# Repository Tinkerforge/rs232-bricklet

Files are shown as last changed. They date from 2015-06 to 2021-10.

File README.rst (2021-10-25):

RS232 Bricklet
==============

This repository contains the firmware source code and the hardware design
files. The documentation generator configs can be found at
https://github.com/Tinkerforge/generators

Repository Content
------------------

software/:
 * examples/: Examples for all supported languages
 * build/: Compiled files
 * src/: Source code of firmware
 * Makefile: Makefile to build project

hardware/:
 * Contains KiCad project files and additionally schematics as PDF

datasheets/:
 * Contains datasheets for sensors and complex ICs that are used

Hardware
--------

The hardware is designed with the open source EDA Suite KiCad
(http://www.kicad.org). Before you are able to open the files,
you have to install the Tinkerforge kicad-libraries
(https://github.com/Tinkerforge/kicad-libraries). You can either clone
them directly in hardware/ or clone them in a separate folder and
symlink them into hardware/
(ln -s kicad_path/kicad-libraries project_path/hardware). After that you
can open the .pro file in hardware/ with KiCad and from there view and
modify the schematics and the PCB layout.

Software
--------

If you want to do your own Brick/Bricklet firmware development we highly
recommend that you use our build environment setup script and read the
tutorial (https://www.tinkerforge.com/en/doc/Tutorials/Tutorial_Build_Environment/Tutorial.html).

To compile the C code we recommend you to install the newest GNU Arm Embedded
Toolchain (https://launchpad.net/gcc-arm-embedded/+download).
You also need to install bricklib (https://github.com/Tinkerforge/bricklib)
and brickletlib (https://github.com/Tinkerforge/brickletlib).

You can either clone it directly in software/src/ or clone it in a
separate folder and symlink it into software/src/
(ln -s bricklib_path/bricklib project_path/software/src/ and
ln -s brickletlib_path/brickletlib project_path/software/src/).
Finally make sure to have CMake installed
(http://www.cmake.org/cmake/resources/software.html).

After that you can build the firmware by invoking make in software/.
The firmware (.bin) can then be found in software/build/ and uploaded
with brickv (click button "Flashing" on start screen).

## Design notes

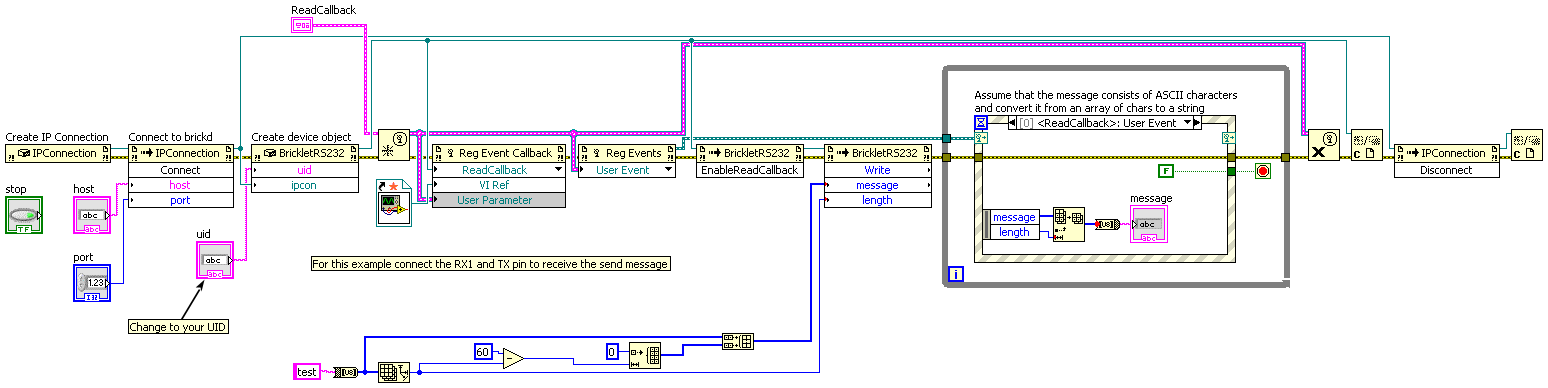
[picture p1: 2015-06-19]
software/examples/labview/Example Loopback.vi.png

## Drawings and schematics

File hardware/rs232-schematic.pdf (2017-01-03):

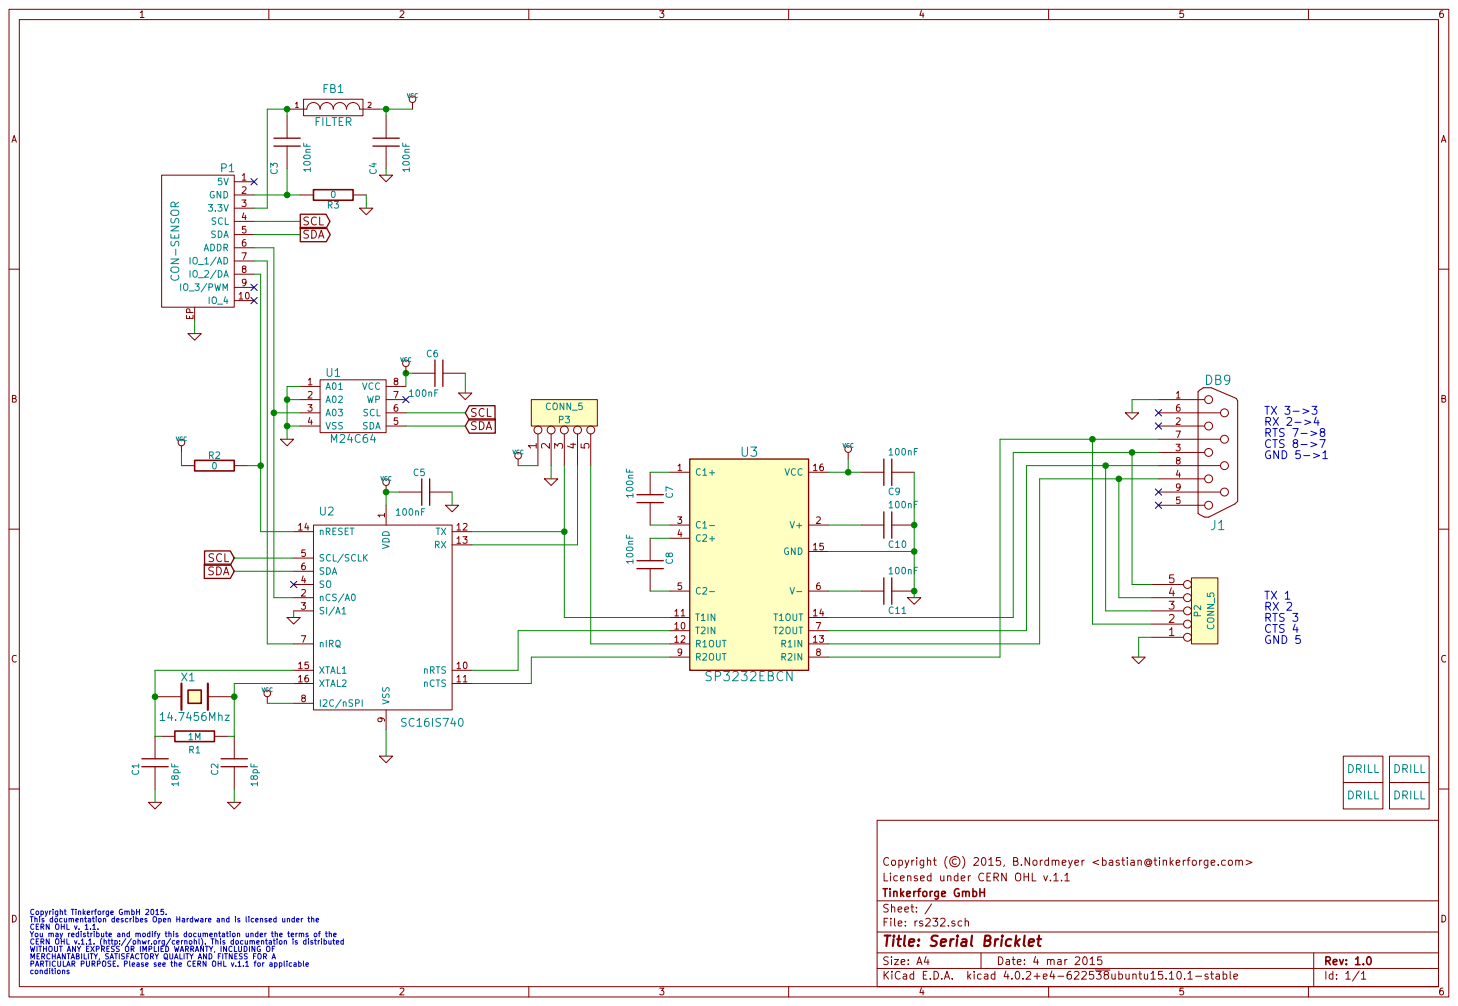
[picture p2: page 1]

Licensed under CERN OHL v.1.1 Copyright (©) 2015, B.Nordmeyer <bastian@tinkerforge.com> VDD

Id: 1/1 Title: Serial Bricklet File: rs232.sch Sheet: / Tinkerforge GmbH

Copyright Tinkerforge GmbH 2015. This documentation describes Open Hardware and is licensed under the CERN OHL v. 1.1. You may redistribute and modify this documentation under the terms of the CERN OHL v.1.1. (http://ohwr.org/cernohl). This documentation is distributed WITHOUT ANY EXPRESS OR IMPLIED WARRANTY, INCLUDING OF MERCHANTABILITY, SATISFACTORY QUALITY AND FITNESS FOR A

PARTICULAR PURPOSE. Please see the CERN OHL v.1.1 for applicable

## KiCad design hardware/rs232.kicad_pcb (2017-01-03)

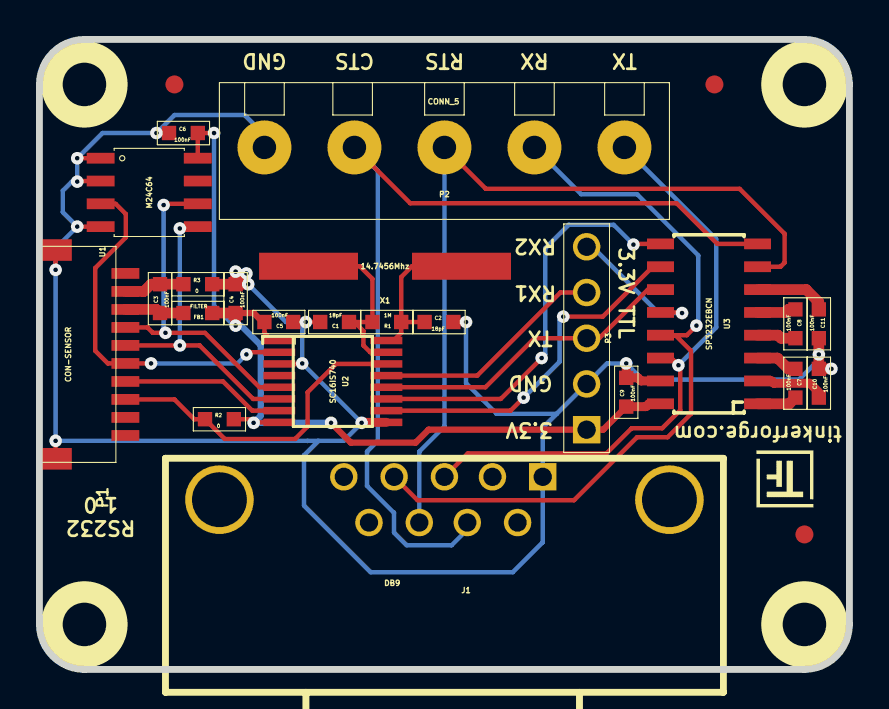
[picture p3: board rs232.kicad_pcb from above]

Board: 2 copper layers, 45.0 x 35.0 mm, 32 parts (0 on the bottom side), 26 nets.

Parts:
C1, C2: 18pF; 0603
C3, C4, C5, C6, C7, C8, C9, C10, C11: 100nF; 0603
FB1: FILTER; 0603
Fiducial_Mark: VAL**; Fiducial_Mark
Fiducial_Mark#2, Fiducial_Mark#3: VAL**; Fiducial_Mark
J1: DB9; SUB09-EU
P1: CON-SENSOR
P2: CONN_5; AKL_5_5
P3: CONN_5; pin_array_5x1
R1: 1M; 0603
R2, R3: 0; 0603
U1: M24C64; SOIC8
U2: SC16IS740; TSSOP16
U3: SP3232EBCN; SOIC16
U4, U5, U6, U7: DRILL; DRILL_NP
VAL: WEEE_7mm
VAL#2: CE_5mm
X1: 14.7456Mhz; HC49_US

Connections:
GND: C1.1, C2.1, C4.1, C5.2, C6.2, C9.1, C10.1, C11.1, J1.1, P1.EP, P2.1, P3.2, R3.1, U1.1, U1.2, U1.4, U2.3, U2.9, U3.15
unnamed: C1.2, R1.1, U2.15, X1.2
unnamed: C2.2, R1.2, U2.16, X1.1
unnamed: C3.1, P1.2, R3.2
unnamed: C3.2, FB1.1, P1.3
unnamed: C7.1, U3.1
unnamed: C7.2, U3.3
unnamed: C8.1, U3.4
unnamed: C8.2, U3.5
unnamed: C10.2, U3.2
unnamed: C11.2, U3.6
unnamed: J1.3, P2.5, U3.14
unnamed: J1.4, P2.4, U3.13
unnamed: J1.7, P2.2, U3.8
unnamed: J1.8, P2.3, U3.7
unnamed: P1.6, U1.3, U2.2
unnamed: P1.7, U2.7
unnamed: P1.8, R2.2, U2.14
unnamed: P3.3, U2.12, U3.11
unnamed: P3.4, U2.13
unnamed: P3.5, U3.12
unnamed: U2.10, U3.10
unnamed: U2.11, U3.9
SCL: P1.4, U1.6, U2.5
SDA: P1.5, U1.5, U2.6
VCC: C4.2, C5.1, C6.1, C9.2, FB1.2, P3.1, R2.1, U1.8, U2.1, U2.8, U3.16

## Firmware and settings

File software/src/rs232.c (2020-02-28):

/* rs232-bricklet
 * Copyright (C) 2015 Olaf Lüke <olaf@tinkerforge.com>
 *
 * rs232.c: Implementation of RS232 Bricklet messages
 *
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
 * You should have received a copy of the GNU Lesser General Public
 * License along with this library; if not, write to the
 * Free Software Foundation, Inc., 59 Temple Place - Suite 330,
 * Boston, MA 02111-1307, USA.
 */

#include "rs232.h"

#include "brickletlib/bricklet_entry.h"
#include "bricklib/bricklet/bricklet_communication.h"
#include "bricklib/utility/util_definitions.h"
#include "config.h"

#define NUM_BAUDRATES 13
#define NUM_PARITIES 5
#define NUM_STOPBITS 2
#define NUM_WORDLENGTH 4
#define NUM_FLOWCONTROL 2

const uint16_t baudrates[NUM_BAUDRATES] = {
	3072, //    300 baud
	1536, //    600 baud
	768,  //   1200 baud
	384,  //   2400 baud
	192,  //   4800 baud
	96,   //   9600 baud
	64,   //  14400 baud
	48,   //  19200 baud
	32,   //  28800 baud
	24,   //  38400 baud
	16,   //  57600 baud
	8,    // 115200 baud
	4     // 230400 baud
};

const uint8_t parities[NUM_PARITIES] = {
	0, // None
	1 << 3, // Odd
	(1 << 3) | (1 << 4), // Even
	(1 << 3) | (1 << 5), // Forced Parity 1
	(1 << 3) | (1 << 4) | (1 << 5), // Forced Parity 0
};

const uint8_t stopbits[NUM_STOPBITS] = {
	0, // 1 Stopbit
	1 << 2 // 2 Stopbits
};

const uint8_t wordlength[NUM_WORDLENGTH] = {
	0, // 5
	1 << 0, // 6
	1 << 1, // 7
	(1 << 0) | (1 << 1) // 8
};

const uint8_t hardware_flowcontrol[NUM_FLOWCONTROL] = {
	0, // Hardware Flow Control Disabled
	(1 << 6) | (1 << 7), // Hardware Flow Control Enabled
};

const uint8_t software_flowcontrol[NUM_FLOWCONTROL] = {
	0, // Software Flow Control Disabled
	(1 << 3) | (1 << 1), // Software Flow Control Enabled
};

uint8_t sc16is740_get_address(void) {
	if(BS->address == I2C_EEPROM_ADDRESS_HIGH) {
		return I2C_ADDRESS_HIGH;
	} else {
		return I2C_ADDRESS_LOW;
	}
}

uint8_t sc16is740_read_fifo(uint8_t *data) {
	int8_t length = BUFFER_SIZE-1 - size_out();
	uint8_t rxlvl = sc16is740_read_register(I2C_INTERNAL_ADDRESS_RXLVL);
	length = MIN(length, rxlvl);

	if(length <= 0) {
		return 0;
	}

	BA->TWID_Read(BA->twid,
	              sc16is740_get_address(),
	              I2C_INTERNAL_ADDRESS_RHR << 3,
	              1,
	              data,
	              length,
	              NULL);

	return length;
}

uint8_t sc16is740_read_register(const uint8_t address) {
	uint8_t value = 0;

	BA->TWID_Read(BA->twid,
	              sc16is740_get_address(),
	              address << 3,
	              1,
	              &value,
	              1,
	              NULL);

	return value;
}

void sc16is740_write_register(const uint8_t address, uint8_t value) {
	BA->TWID_Write(BA->twid,
	               sc16is740_get_address(),
	               address << 3,
	               1,
	               &value,
	               1,
	               NULL);
}

void sc16is740_reconfigure(void) {
	BrickletAPI *ba = BA;
	if(ba->mutex_take(*ba->mutex_twi_bricklet, 10)) {
		ba->bricklet_select(BS->port - 'a');

		// Write 0xBF to LCR to be able to access EFR
		sc16is740_write_register(I2C_INTERNAL_ADDRESS_LCR, 0xBF);

		// Enable or Disable Hardware Flow Control
		sc16is740_write_register(I2C_INTERNAL_ADDRESS_EFR, hardware_flowcontrol[BC->hardware_flowcontrol] | software_flowcontrol[BC->software_flowcontrol]);

		// Configure UART
		uint8_t lcr = stopbits[BC->stopbits-1] | parities[BC->parity] | wordlength[BC->wordlength-5];
		sc16is740_write_register(I2C_INTERNAL_ADDRESS_LCR, lcr);

		// Configure baudrate: ((14.7456 MHz * 1000000) / 1) /
		//                     (X baud * 16) = baudrates[BC->baudrate]
		lcr |= 1 << 7; // Divisor latch enable: LCR[7] = 1
		sc16is740_write_register(I2C_INTERNAL_ADDRESS_LCR, lcr);

		sc16is740_write_register(I2C_INTERNAL_ADDRESS_DLL, baudrates[BC->baudrate]&0xFF);
		sc16is740_write_register(I2C_INTERNAL_ADDRESS_DLH, (baudrates[BC->baudrate]>>8)&0xFF);

		lcr = sc16is740_read_register(I2C_INTERNAL_ADDRESS_LCR);
		lcr &= ~(1 << 7); // Divisor latch disable: LCR[7] = 0
		sc16is740_write_register(I2C_INTERNAL_ADDRESS_LCR, lcr);

		ba->bricklet_deselect(BS->port - 'a');
		ba->mutex_give(*ba->mutex_twi_bricklet);
	}
}

void sc16is740_init(void) {
	BrickletAPI *ba = BA;
	if(ba->mutex_take(*ba->mutex_twi_bricklet, 10)) {
		ba->bricklet_select(BS->port - 'a');

		// Enable RX and TX FIFOs: FCR[0] = 1
		sc16is740_write_register(I2C_INTERNAL_ADDRESS_FCR, 1 << 0);

		// Enable Receive Holding Register Interrupt: IER[0] = 1
		sc16is740_write_register(I2C_INTERNAL_ADDRESS_IER, 1 << 0);

		ba->bricklet_deselect(BS->port - 'a');
		ba->mutex_give(*ba->mutex_twi_bricklet);
	}
}

void constructor(void) {
	_Static_assert(sizeof(BrickContext) <= BRICKLET_CONTEXT_MAX_SIZE,
	               "BrickContext too big");

    BrickContext *bc = BC;

	PIN_NIRQ.type = PIO_INPUT;
	PIN_NIRQ.attribute = PIO_PULLUP;
	BA->PIO_Configure(&PIN_NIRQ, 1);

	// Always keep NRESET to high, with newer hardware versions
	// NRESET is directly connected to VCC. This is necessary to
	// prevent rare EMI problems that result in unexpected resets.
	PIN_NRESET.type = PIO_OUTPUT_1;
	PIN_NRESET.attribute = PIO_DEFAULT;
	BA->PIO_Configure(&PIN_NRESET, 1);

	bc->read_callback_enabled = false;
	bc->frame_readable_cb_frame_size = 0;
	bc->frame_readable_cb_already_sent = false;
	bc->in_sync = true;

	bc->baudrate = 11;
	bc->parity = 0;
	bc->stopbits = 1;
	bc->wordlength = 8;
	bc->hardware_flowcontrol = 0;
	bc->software_flowcontrol = 0;
	bc->error = 0;

	read_configuration_from_eeprom();
	sc16is740_init();
	sc16is740_reconfigure();
}

void destructor(void) {
}

uint8_t size_in(void) {
	BrickContext *bc = BC;
	if(bc->in_start == bc->in_end) {
		return 0;
	}

	if(bc->in_start < bc->in_end) {
		return bc->in_end - bc->in_start;
	}

	return (BUFFER_SIZE - bc->in_start) + bc->in_end;
}

uint8_t size_out(void) {
	BrickContext *bc = BC;
	if(bc->out_start == bc->out_end) {
		return 0;
	}

	if(bc->out_start < bc->out_end) {
		return bc->out_end - bc->out_start;
	}

	return (BUFFER_SIZE - bc->out_start) + bc->out_end;
}

bool new_char_out(char out) {
	BrickContext *bc = BC;
	bc->out[bc->out_end] = out;

	// If buffer is full, we ignore new char
	if((bc->out_end+1) % BUFFER_SIZE != bc->out_start) {
		bc->out_end = (bc->out_end + 1) % BUFFER_SIZE;
		return true;
	}

	return false;
}

bool get_char_in(char *c) {
	BrickContext *bc = BC;
	if(bc->in_start != bc->in_end) {
		*c = bc->in[bc->in_start];
		bc->in_start = (bc->in_start + 1) % BUFFER_SIZE;
		return true;
	}

	return false;
}

bool is_irq(void) {
	return (!(PIN_NIRQ.pio->PIO_PDSR & PIN_NIRQ.mask)) && (size_out() < (BUFFER_SIZE-1));
}

bool try_read_data(void) {
	while(is_irq()) {
		uint8_t buffer[59];
		uint8_t length = sc16is740_read_fifo(buffer);
		if(length == 0) {
			return false;
		}

		for(uint8_t i = 0; i < length; i++) {
			// We don't have to check return value here, sc16is740_read_fifo
			// already made sure that there is enough space in the buffer.
			new_char_out(buffer[i]);
		}
		return true;
	}

	return false;
}
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

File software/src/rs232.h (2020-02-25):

/* rs232-bricklet
 * Copyright (C) 2015 Olaf Lüke <olaf@tinkerforge.com>
 *
 * rs232.h: Implementation of RS232 Bricklet messages
 *
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
 * You should have received a copy of the GNU Lesser General Public
 * License along with this library; if not, write to the
 * Free Software Foundation, Inc., 59 Temple Place - Suite 330,
 * Boston, MA 02111-1307, USA.
 */

#ifndef RS232_H
#define RS232_H

#include <stdint.h>

#include "bricklib/com/com_common.h"

#define CONFIGURATION_EEPROM_POSITION (BRICKLET_PLUGIN_MAX_SIZE + 96)

#define FID_WRITE                    1
#define FID_READ                     2
#define FID_ENABLE_READ_CALLBACK     3
#define FID_DISABLE_READ_CALLBACK    4
#define FID_IS_READ_CALLBACK_ENABLED 5
#define FID_SET_CONFIGURATION        6
#define FID_GET_CONFIGURATION        7
#define FID_READ_CALLBACK            8
#define FID_ERROR_CALLBACK           9
#define FID_SET_BREAK_CONDITION      10
#define FID_SET_FRAME_READABLE_CALLBACK_CONFIGURATION 11
#define FID_GET_FRAME_READABLE_CALLBACK_CONFIGURATION 12
#define FID_FRAME_READABLE_CALLBACK 13
#define FID_READ_FRAME 14

#define MESSAGE_LENGTH 60

typedef struct {
	MessageHeader header;
} __attribute__((__packed__)) StandardMessage;

typedef struct {
	MessageHeader header;
	char message[MESSAGE_LENGTH];
	uint8_t length;
} __attribute__((__packed__)) Write;

typedef struct {
	MessageHeader header;
	uint8_t written;
} __attribute__((__packed__)) WriteReturn;

typedef struct {
	MessageHeader header;
} __attribute__((__packed__)) Read;

typedef struct {
	MessageHeader header;
	char message[MESSAGE_LENGTH];
	uint8_t length;
} __attribute__((__packed__)) ReadReturn;

typedef struct {
	MessageHeader header;
} __attribute__((__packed__)) EnableReadCallback;

typedef struct {
	MessageHeader header;
} __attribute__((__packed__)) DisableReadCallback;

typedef struct {
	MessageHeader header;
} __attribute__((__packed__)) IsReadCallbackEnabled;

typedef struct {
	MessageHeader header;
	bool enabled;
} __attribute__((__packed__)) IsReadCallbackEnabledReturn;

typedef struct {
	MessageHeader header;
	uint8_t baudrate;
	char parity;
	uint8_t stopbits;
	uint8_t wordlength;
	uint8_t hardware_flowcontrol;
	uint8_t software_flowcontrol;
} __attribute__((__packed__)) SetConfiguration;

typedef struct {
	MessageHeader header;
} __attribute__((__packed__)) GetConfiguration;

typedef struct {
	MessageHeader header;
	uint8_t baudrate;
	uint8_t parity;
	uint8_t stopbits;
	uint8_t wordlength;
	uint8_t hardware_flowcontrol;
	uint8_t software_flowcontrol;
} __attribute__((__packed__)) GetConfigurationReturn;

typedef struct {
	MessageHeader header;
	char message[MESSAGE_LENGTH];
	uint8_t length;
} __attribute__((__packed__)) ReadCallback;

typedef struct {
	MessageHeader header;
	uint8_t error;
} __attribute__((__packed__)) ErrorCallback;

typedef struct {
	MessageHeader header;
	uint16_t break_time;
} __attribute__((__packed__)) SetBreakCondition;

typedef struct {
	MessageHeader header;
	uint8_t frame_size;
} __attribute__((__packed__)) SetFrameReadableCallbackConfiguration;

typedef struct {
	MessageHeader header;
} __attribute__((__packed__)) GetFrameReadableCallbackConfiguration;

typedef struct {
	MessageHeader header;
	uint8_t frame_size;
} __attribute__((__packed__)) GetFrameReadableCallbackConfigurationReturn;

typedef struct {
	MessageHeader header;
	uint8_t frame_count;
} __attribute__((__packed__)) FrameReadableCallback;

typedef struct {
	MessageHeader header;
} __attribute__((__packed__)) ReadFrame;

void read(const ComType com, const Read *data, const uint8_t length);
void write(const ComType com, const Write *data);
void enable_read_callback(const ComType com, const EnableReadCallback *data);
void disable_read_callback(const ComType com, const DisableReadCallback *data);
void is_read_callback_enabled(const ComType com, const IsReadCallbackEnabled *data);
void set_configuration(const ComType com, const SetConfiguration *data);
void get_configuration(const ComType com, const GetConfiguration *data);
void set_break_condition(const ComType com, const SetBreakCondition *data);
void set_frame_readable_callback_configuration(const ComType com, const SetFrameReadableCallbackConfiguration *data);
void get_frame_readable_callback_configuration(const ComType com, const GetFrameReadableCallbackConfiguration *data);


#define I2C_EEPROM_ADDRESS_HIGH 84

#define I2C_ADDRESS_HIGH 76 // 0b1001100
#define I2C_ADDRESS_LOW 77 // 0b1001101

#define I2C_INTERNAL_ADDRESS_RHR 0x00
#define I2C_INTERNAL_ADDRESS_THR 0x00
#define I2C_INTERNAL_ADDRESS_IER 0x01
#define I2C_INTERNAL_ADDRESS_FCR 0x02
#define I2C_INTERNAL_ADDRESS_IIR 0x02
#define I2C_INTERNAL_ADDRESS_LCR 0x03
#define I2C_INTERNAL_ADDRESS_LSR 0x05
#define I2C_INTERNAL_ADDRESS_TXLVL 0x08
#define I2C_INTERNAL_ADDRESS_RXLVL 0x09

#define I2C_INTERNAL_ADDRESS_DLL 0x00
#define I2C_INTERNAL_ADDRESS_DLH 0x01
#define I2C_INTERNAL_ADDRESS_EFR 0x02
#define I2C_INTERNAL_ADDRESS_MCR 0x04

#define SC16IS740_LSR_DATA_IN_RECEIVER (1 << 0)
#define SC16IS740_LSR_OVERRUN_ERROR    (1 << 1)
#define SC16IS740_LSR_THR_IS_EMPTY     (1 << 5)

void sc16is740_init(void);
uint8_t sc16is740_get_address(void);
uint8_t sc16is740_read_register(const uint8_t address);
void sc16is740_write_register(const uint8_t address, uint8_t value);
void sc16is740_reset(void);
void write_configuration_to_eeprom(void);
void read_configuration_from_eeprom(void);

uint8_t size_in(void);
uint8_t size_out(void);

void invocation(const ComType com, const uint8_t *data);
void constructor(void);
void destructor(void);
void tick(const uint8_t tick_type);

#endif

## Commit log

2015-03-26 add hardware files for rs232 bricklet
    [rs232.kicad_pcb, rs232.sch]
2015-03-26 add schematic
    [rs232.sch]
2015-04-02 run drc
    [rs232.kicad_pcb]
2015-04-24 drc executed
    [rs232.kicad_pcb]
2015-08-07 Use full device class name in Python example
2015-08-18 Make reading of RHR register more efficient
    * This should allow longer bursts with higher bandwith
    * Also add callbacks for overrun, framing and parity errors
    [rs232.c, rs232.h]
2016-05-18 c: Add missing device destroy call
2016-11-08 Make sure we don't have uncessary i2c select/deselect
2016-11-08 fix source code bugs, no compiling
    [rs232.c]
2016-11-08 Make sure we always call select before i2c read
2016-12-09 fix baudrate setting bug
    baudrate settings were not working for baudrates lower than 4800 baud
    [rs232.c]
2017-01-03 hardware adaption: fix reset to ground
    [rs232.kicad_pcb, rs232.sch]
2017-01-09 Change RESET beahvior to be compatible with new hardware version
    [rs232.c]
2018-02-20 Cleanup KiCad libraries config
    Ensure LibDir=kicad-libraries and LibName1=tinkerforge.
    Remove special library.
2020-02-25 Add frame available callback and read frame function.
2021-10-25 Update KiCad link
    https://www.kicad.org/blog/2021/10/Avoid-links-to-former-kicad-domain/
